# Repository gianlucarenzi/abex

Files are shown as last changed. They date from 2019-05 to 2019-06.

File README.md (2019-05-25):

Atari Bus EXtender for Atari XE Computers
=====================================

This is a Atari PBI & ECI Bus extender, for adding expansion board with ease,
called Atari Bus EXtender for Atari XE Computers or ABEX for short.

This project expand somehow the Atari 1090XL Bus Expansion in the early 80s
but with a simple layout and using only 3.3v compliant electronics.
No 5V is available on the bus, and all signals are converted to 3.3v level.

The Bus recall somehow the AteoBus from Amiga 1200 Computers but using a
more common nowadays PCI-Express Bus Slots with 64 pins.

Right now there are 2 boards desinged for this bus:

1- Atari DUO Cart (a porting of the famous Uno-Cart Project)

2- Atari MegaRAM (a PortB PIA Emulator) with 1024K RAM memory banked

More boards can be added as soon they do not interfere with the others
like using the PBI Protocol device in available in ROM. For example a simple
RS232 Board can be designed using a STM32F407 as port EXPANDER with R: handler
in internal flash, or a SDCard Hard Drive Simulator can be designed as well.

Even WiFi or Ethernet Controller can be achived flawlessly.

Everything is up to you, using your mind to open the world to this wonderful
machine like Atari 130XE.

Rendered Images
===============
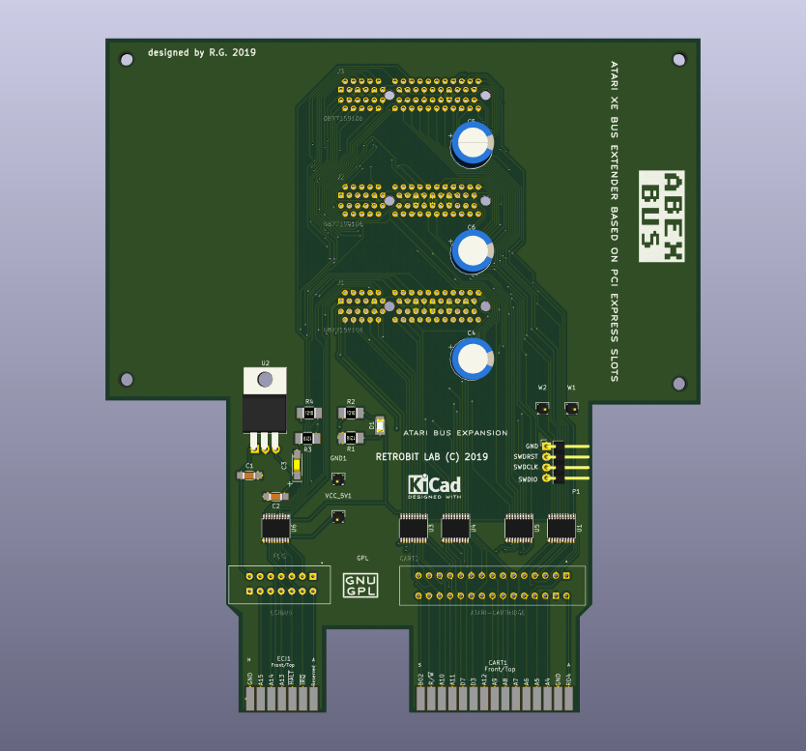
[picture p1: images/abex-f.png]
Board Front
# Front
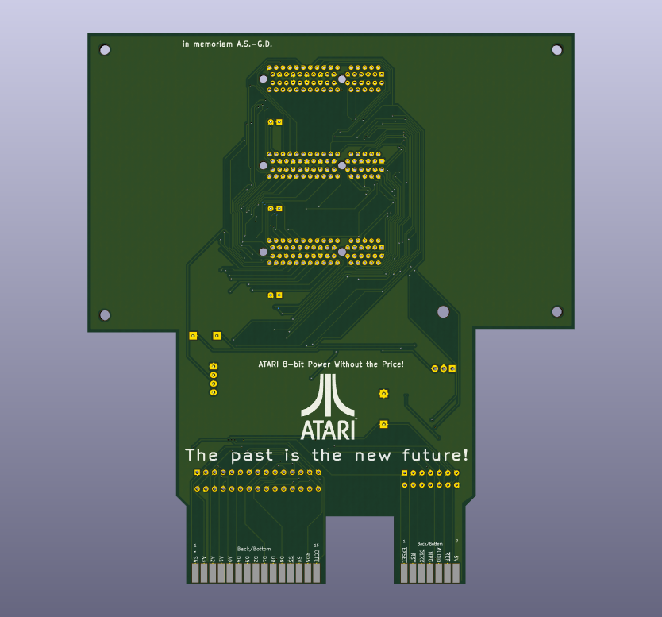
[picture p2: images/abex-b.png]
Board Back
# Back
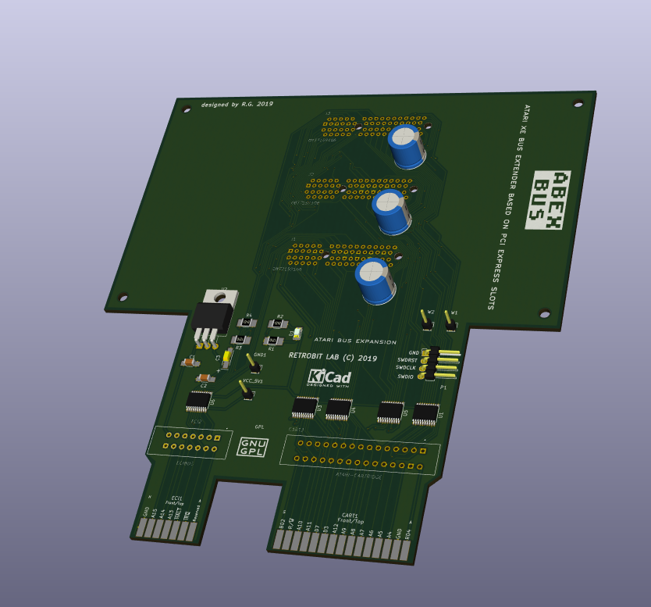
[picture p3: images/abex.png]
Board Overall
# Overall

Hardware License
================
Copyright (C) 2018/2019 Gianluca Renzi <gianlucarenzi@eurek.it> <icjtqr@gmail.com>

The hardware of this project is released as free/open hardware under the
Creative Commons Attribution Share-Alike license. See `LICENSE.hw` for details.

Firmware License
================
Copyright (C) 2019 Gianluca Renzi <icjtqr@gmail.com>

The microcontroller firmware of this project is released as free software,
under the terms of the GNU General Public License v3, or later.  See
`LICENSE.sw` for details.

Software License
================
The host software (amigafloppy tool) is released as free software, under the
terms of the GNU General Public License v3, or later. See `LICENSE.sw` or licence.txt for
details.

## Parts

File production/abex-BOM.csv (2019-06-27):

Id | Designator | Package | Quantity | Designation | Supplier and ref
1 | REF** | KiCad-Logo2_5mm_SilkScreen | 1 | KiCad-Logo2_5mm_SilkScreen
2 | GPL | Symbol_GNU-GPL_SilkScreen_Small | 1 | Symbol_GNU-GPL_CopperTop_Small
3 | LOGO | ABEX_Logo_22mmx11mm_WB | 1 | LOGO
4 | C1,C7,C8,C9 | C_1206_HandSoldering | 4 | 10u
5 | C2 | C_1206_HandSoldering | 1 | 100n
6 | C3 | TantalC_SizeA_EIA-3216_HandSoldering | 1 | 22u
7 | CART1 | ATARI-LEFT-CARTRIDGE | 1 | ATARI-CARTRIDGE
8 | CART2 | TE_5530843-2_15X2_CART_EDGE_CONNECTOR | 1 | ATARI-CARTRIDGE
9 | D1 | LED_1206 | 1 | LED GREEN
10 | ECI1 | ATARI-XE-ECI-SLOT | 1 | ECIBUS
11 | R1 | R_1210_HandSoldering | 1 | 1.5K
12 | R2,R4,R3 | R_1210_HandSoldering | 3 | 0
13 | U1,U3,U4,U5,U6 | SSOP-20_4.4x6.5mm_Pitch0.65mm | 5 | TXB0108-PW
14 | W1,W2,GND1,VCC_5V1 | Pin_Header_Straight_1x01 | 4 | TEST_1P
15 | J4,J5,J6,J7 | MountingHole_3mm | 4 | Conn_01x01
16 | ECI2 | ECI_BUS_7X2_EDGE_CONNECTOR | 1 | ECIBUS
17 | P1 | Pin_Header_Angled_1x04 | 1 | CONN_01X04
18 | C4,C5,C6 | CP_Radial_D10.0mm_P2.50mm_3D | 3 | 10u
19 | U2 | MCP_1827S_TO-220-3_Horizontal_TabDown | 1 | MCP1827S-1.5A-TO-220-3
20 | J1,J2,J3 | MOLEX_0877159106 | 3 | 0877159106
21 | ATARILOGO | atari_fuji_SilkScreen_21.2x25-Rev | 1 | LOGO

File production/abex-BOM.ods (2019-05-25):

Id | Designator | Package | Quantity | Designation | Codice componente | Codice produttore | Descrizione
1 | J1,J2,J3 | ISA_BUS_CONNECTOR_62PIN | 3 | Bus_ISA_8bit_for_ATARI_8bit | EBC31DCWN-S371-ND | EBC31DCWN-S371 | CONN ISA FEMALE 62POS 0.100 GOLD
2 | C1 | C_1206_HandSoldering | 1 | 10u | 445-9985-1-ND | CGA5L1X7R1E106M160AD | CAP CER 10UF 25V X7R 1206 EPOXY
3 | C2 | C_1206_HandSoldering | 1 | 100n | 720-1803-1-ND | VJ1206Y104KXJPW1BC | CAP CER 0.1UF 16V X7R 1206
4 | C3 | TantalC_SizeA_EIA-3216_HandSoldering | 1 | 22u | 399-3692-1-ND | T491A226M010AT | CAP TANT 22UF 20% 10V 1206
5 | CART1 | ATARI-LEFT-CARTRIDGE | 1 | ATARI-CARTRIDGE
6 | CART2 | TE_5530843-2_15X2_CART_EDGE_CONNECTOR | 1 | ATARI-CARTRIDGE | A31715-ND | 5530843-2 | CONN CARDEDGE FEMALE 30POS 0.100
7 | D1 | LED_1206 | 1 | LED GREEN | 160-1166-1-ND | LTST-C150AKT | LED AMBER CLEAR SMD
8 | ECI1 | ATARI-XE-ECI-SLOT | 1 | ECIBUS
9 | R1 | R_1210_HandSoldering | 1 | 1.5K | RMCF1210FT1K50CT-ND | RMCF1210FT1K50 | RES 1.5K OHM 1% 1/3W 1210
10 | R2,R4,R5 | R_1210_HandSoldering | 3 | 0 | RMCF1210ZT0R00CT-ND | RMCF1210ZT0R00 | RES 0 OHM JUMPER 1/2W 1210
11 | U1,U2,U3,U4,U5 | SSOP-20_4.4x6.5mm_Pitch0.65mm | 5 | TXB0108-PW | 296-21527-1-ND | TXB0108PWR | IC TRNSLTR BIDIRECTIONAL 20TSSOP
12 | U6 | MCP_1827S_TO-220-3_Horizontal_TabDown | 1 | MCP1827S-1.5A-TO-220-3 | MCP1827S-3302E/AB-ND | MCP1827S-3302E/AB | IC REG LINEAR 3.3V 1.5A TO220-3
13 | W1,W2,GND1,VCC_5V1 | Pin_Header_Straight_1x01 | 4 | TEST_1P | 609-3301-ND | 68002-210HLF | CONN HEADER VERT 10POS 2.54MM
14 | J4,J5,J6,J7 | MountingHole_3mm | 4 | Conn_01x01 | 609-3301-ND | 68002-210HLF | CONN HEADER VERT 10POS 2.54MM
15 | P1 | Pin_Header_Angled_1x04 | 1 | CONN_01X04 | 609-3407-ND | 68016-404HLF | CONN HEADER R/A 4POS 2.54MM
16 | ECI2 | ECI_BUS_7X2_EDGE_CONNECTOR | 1 | ECIBUS | S9712-ND | ECC07DRTN | CONN EDGE DUAL FMALE 14POS 0.100
17 | GNU | Symbol_GNU-GPL_SilkScreen_Small | 1 | Symbol_GNU-GPL_CopperTop_Small
18 | REF** | KiCad-Logo2_8mm_SilkScreen | 1 | KiCad-Logo2_8mm_SilkScreen
19 | G*** | ABEX_Logo_22mmx11mm_WB | 1 | LOGO
20 | G*** | atari_800_XL_BW_25x25 | 1 | LOGO

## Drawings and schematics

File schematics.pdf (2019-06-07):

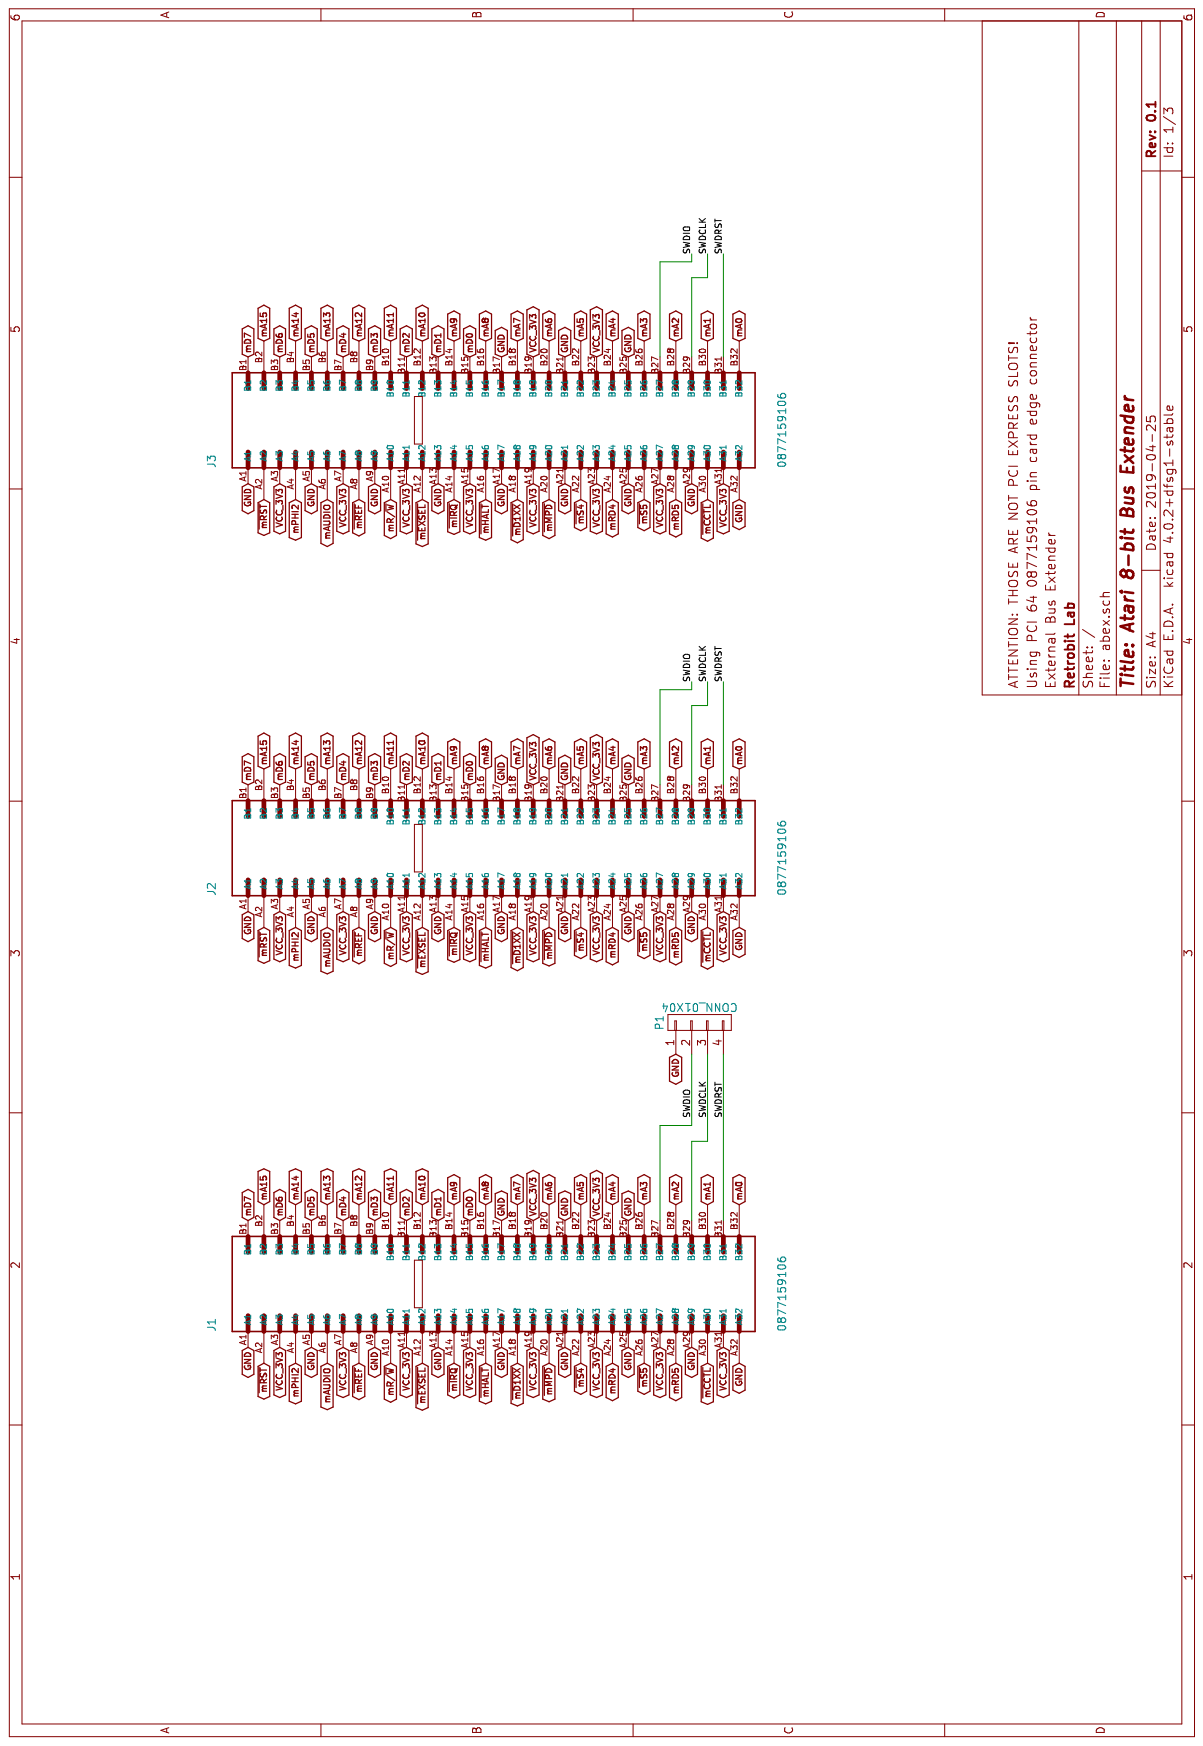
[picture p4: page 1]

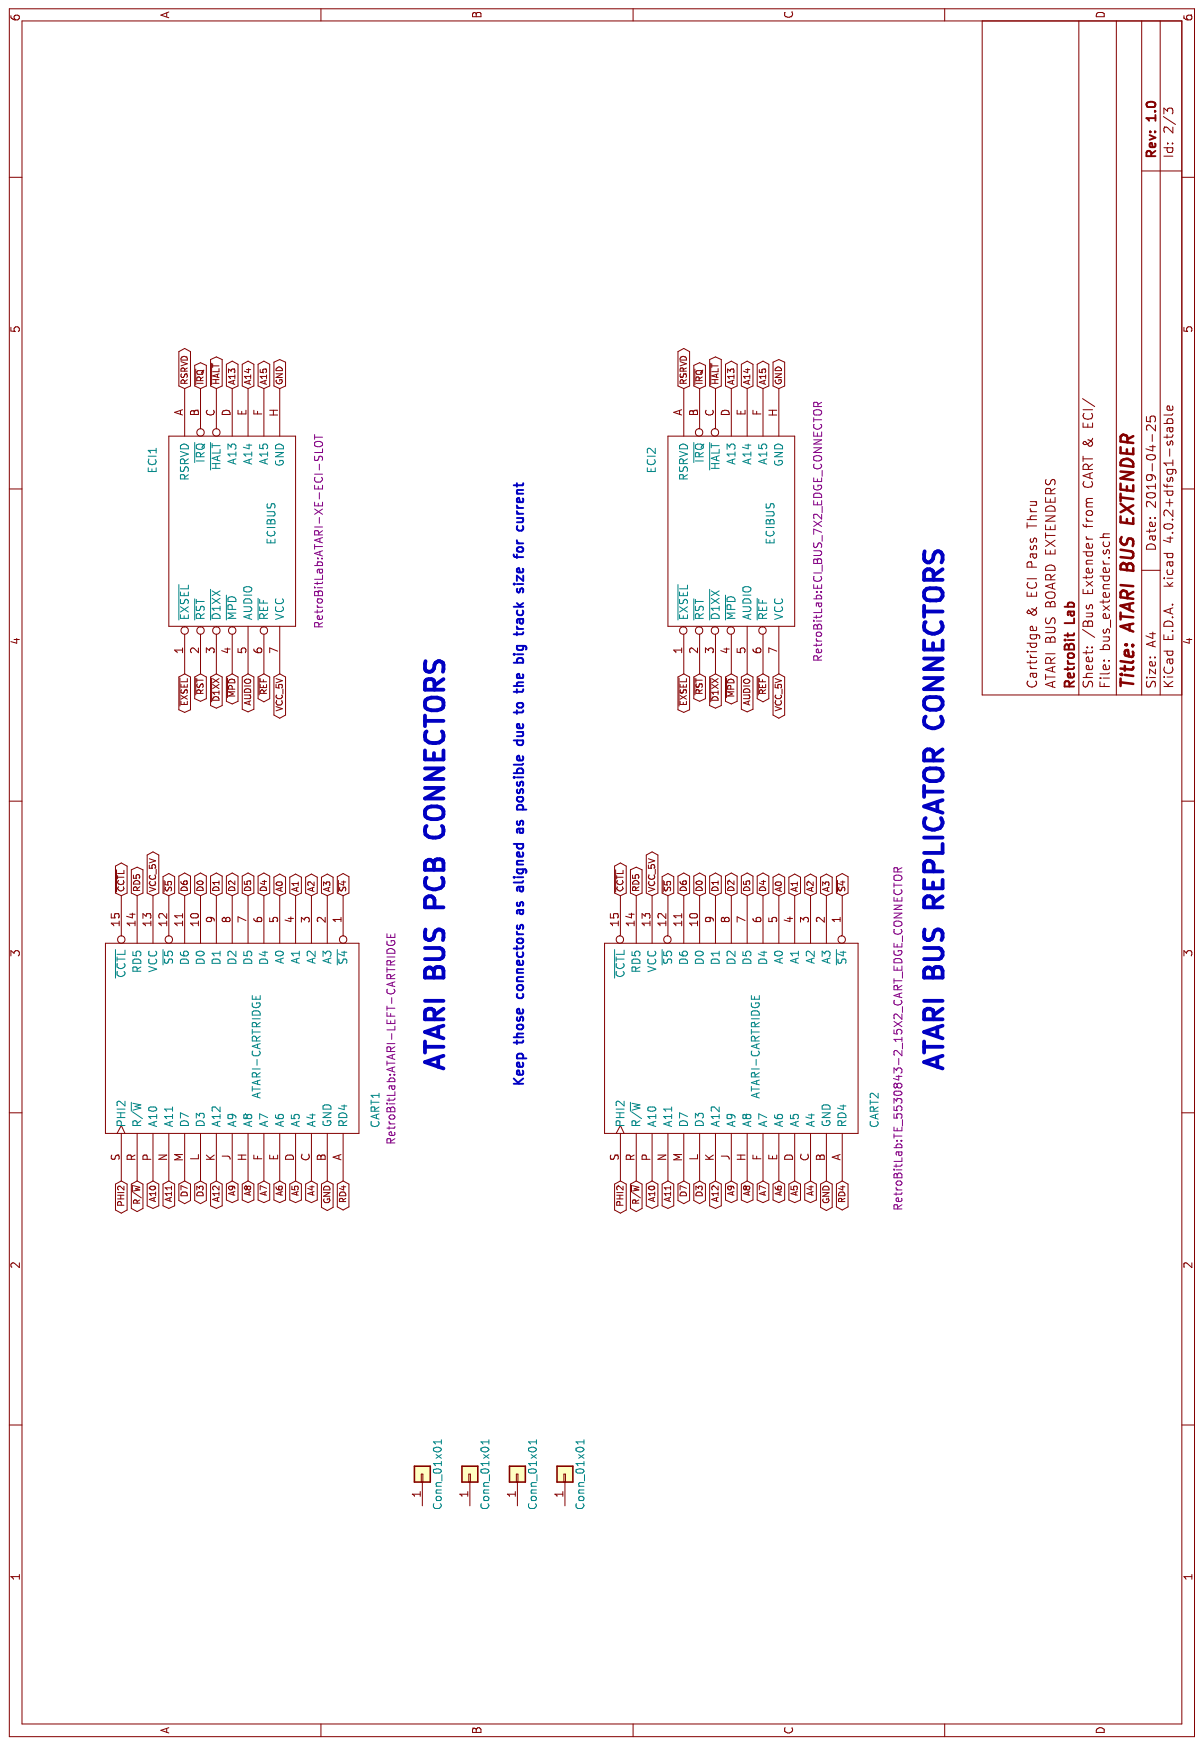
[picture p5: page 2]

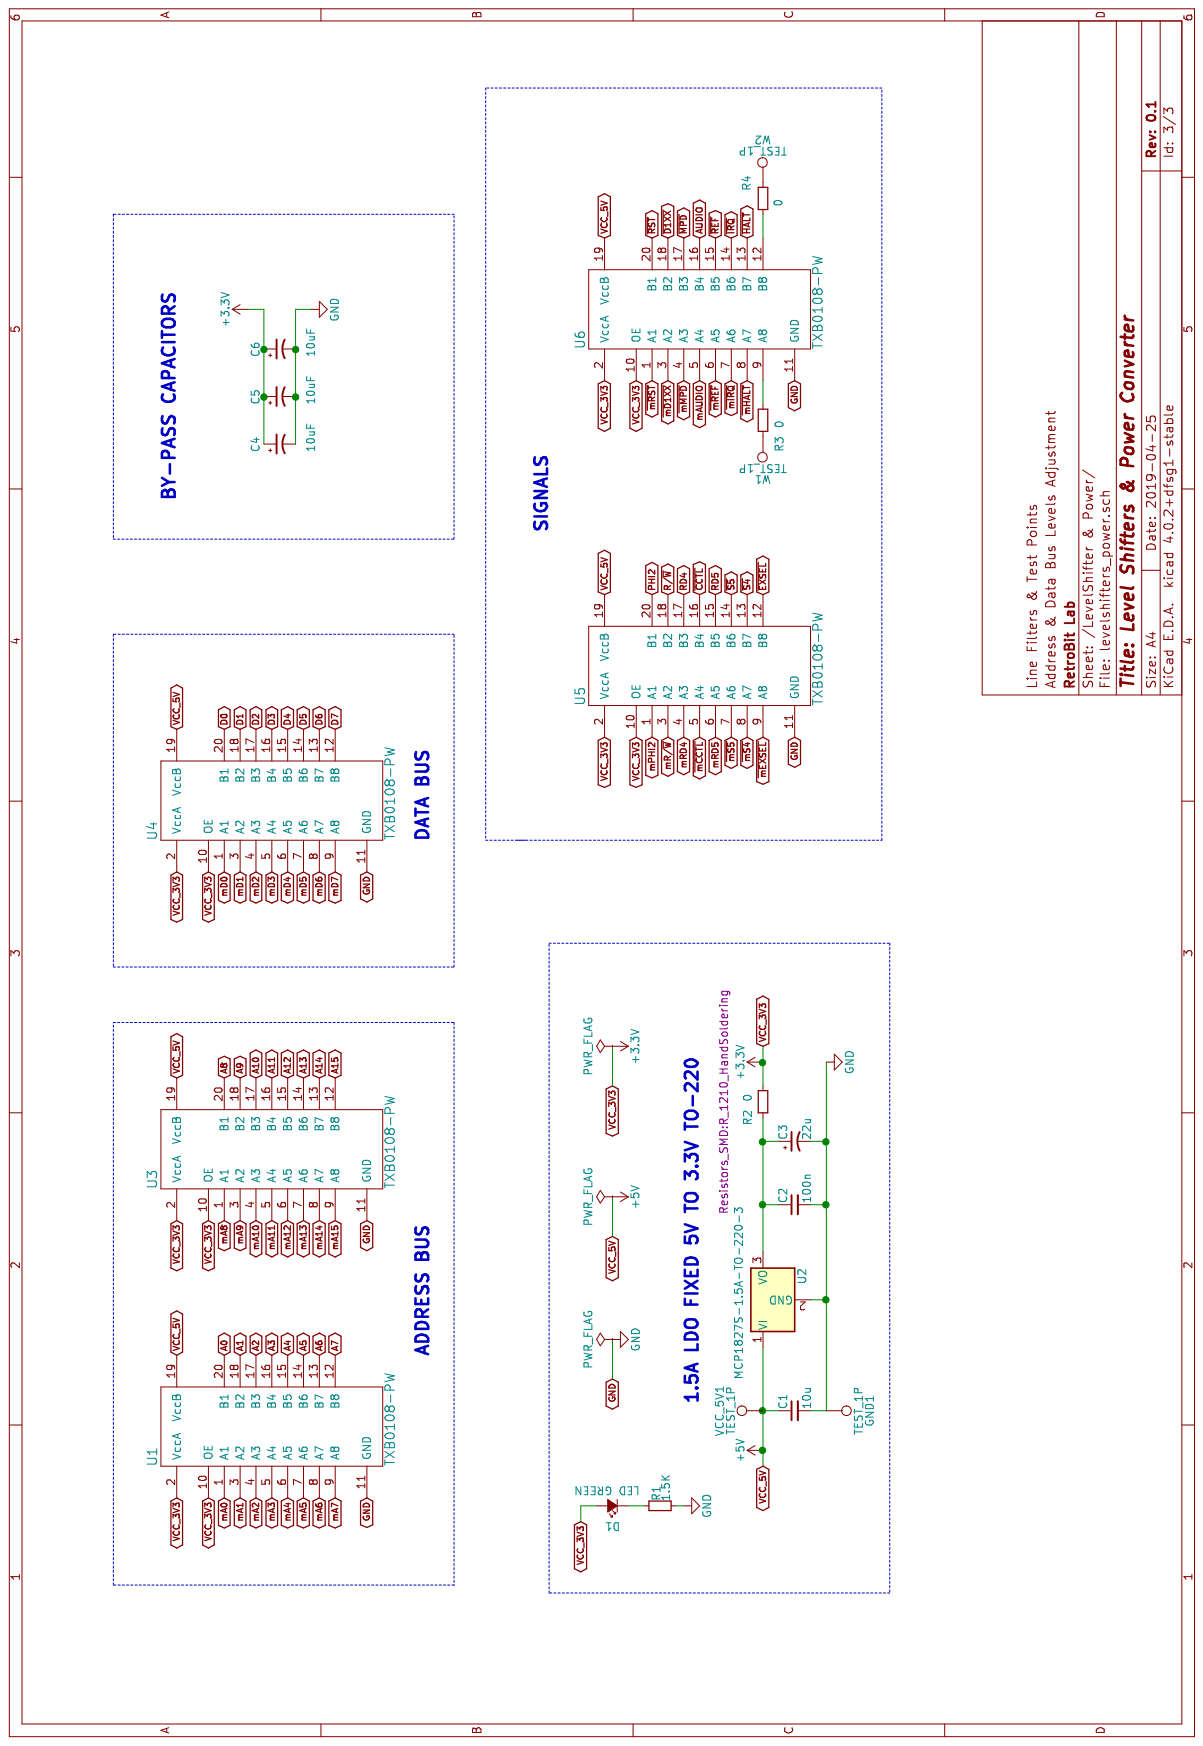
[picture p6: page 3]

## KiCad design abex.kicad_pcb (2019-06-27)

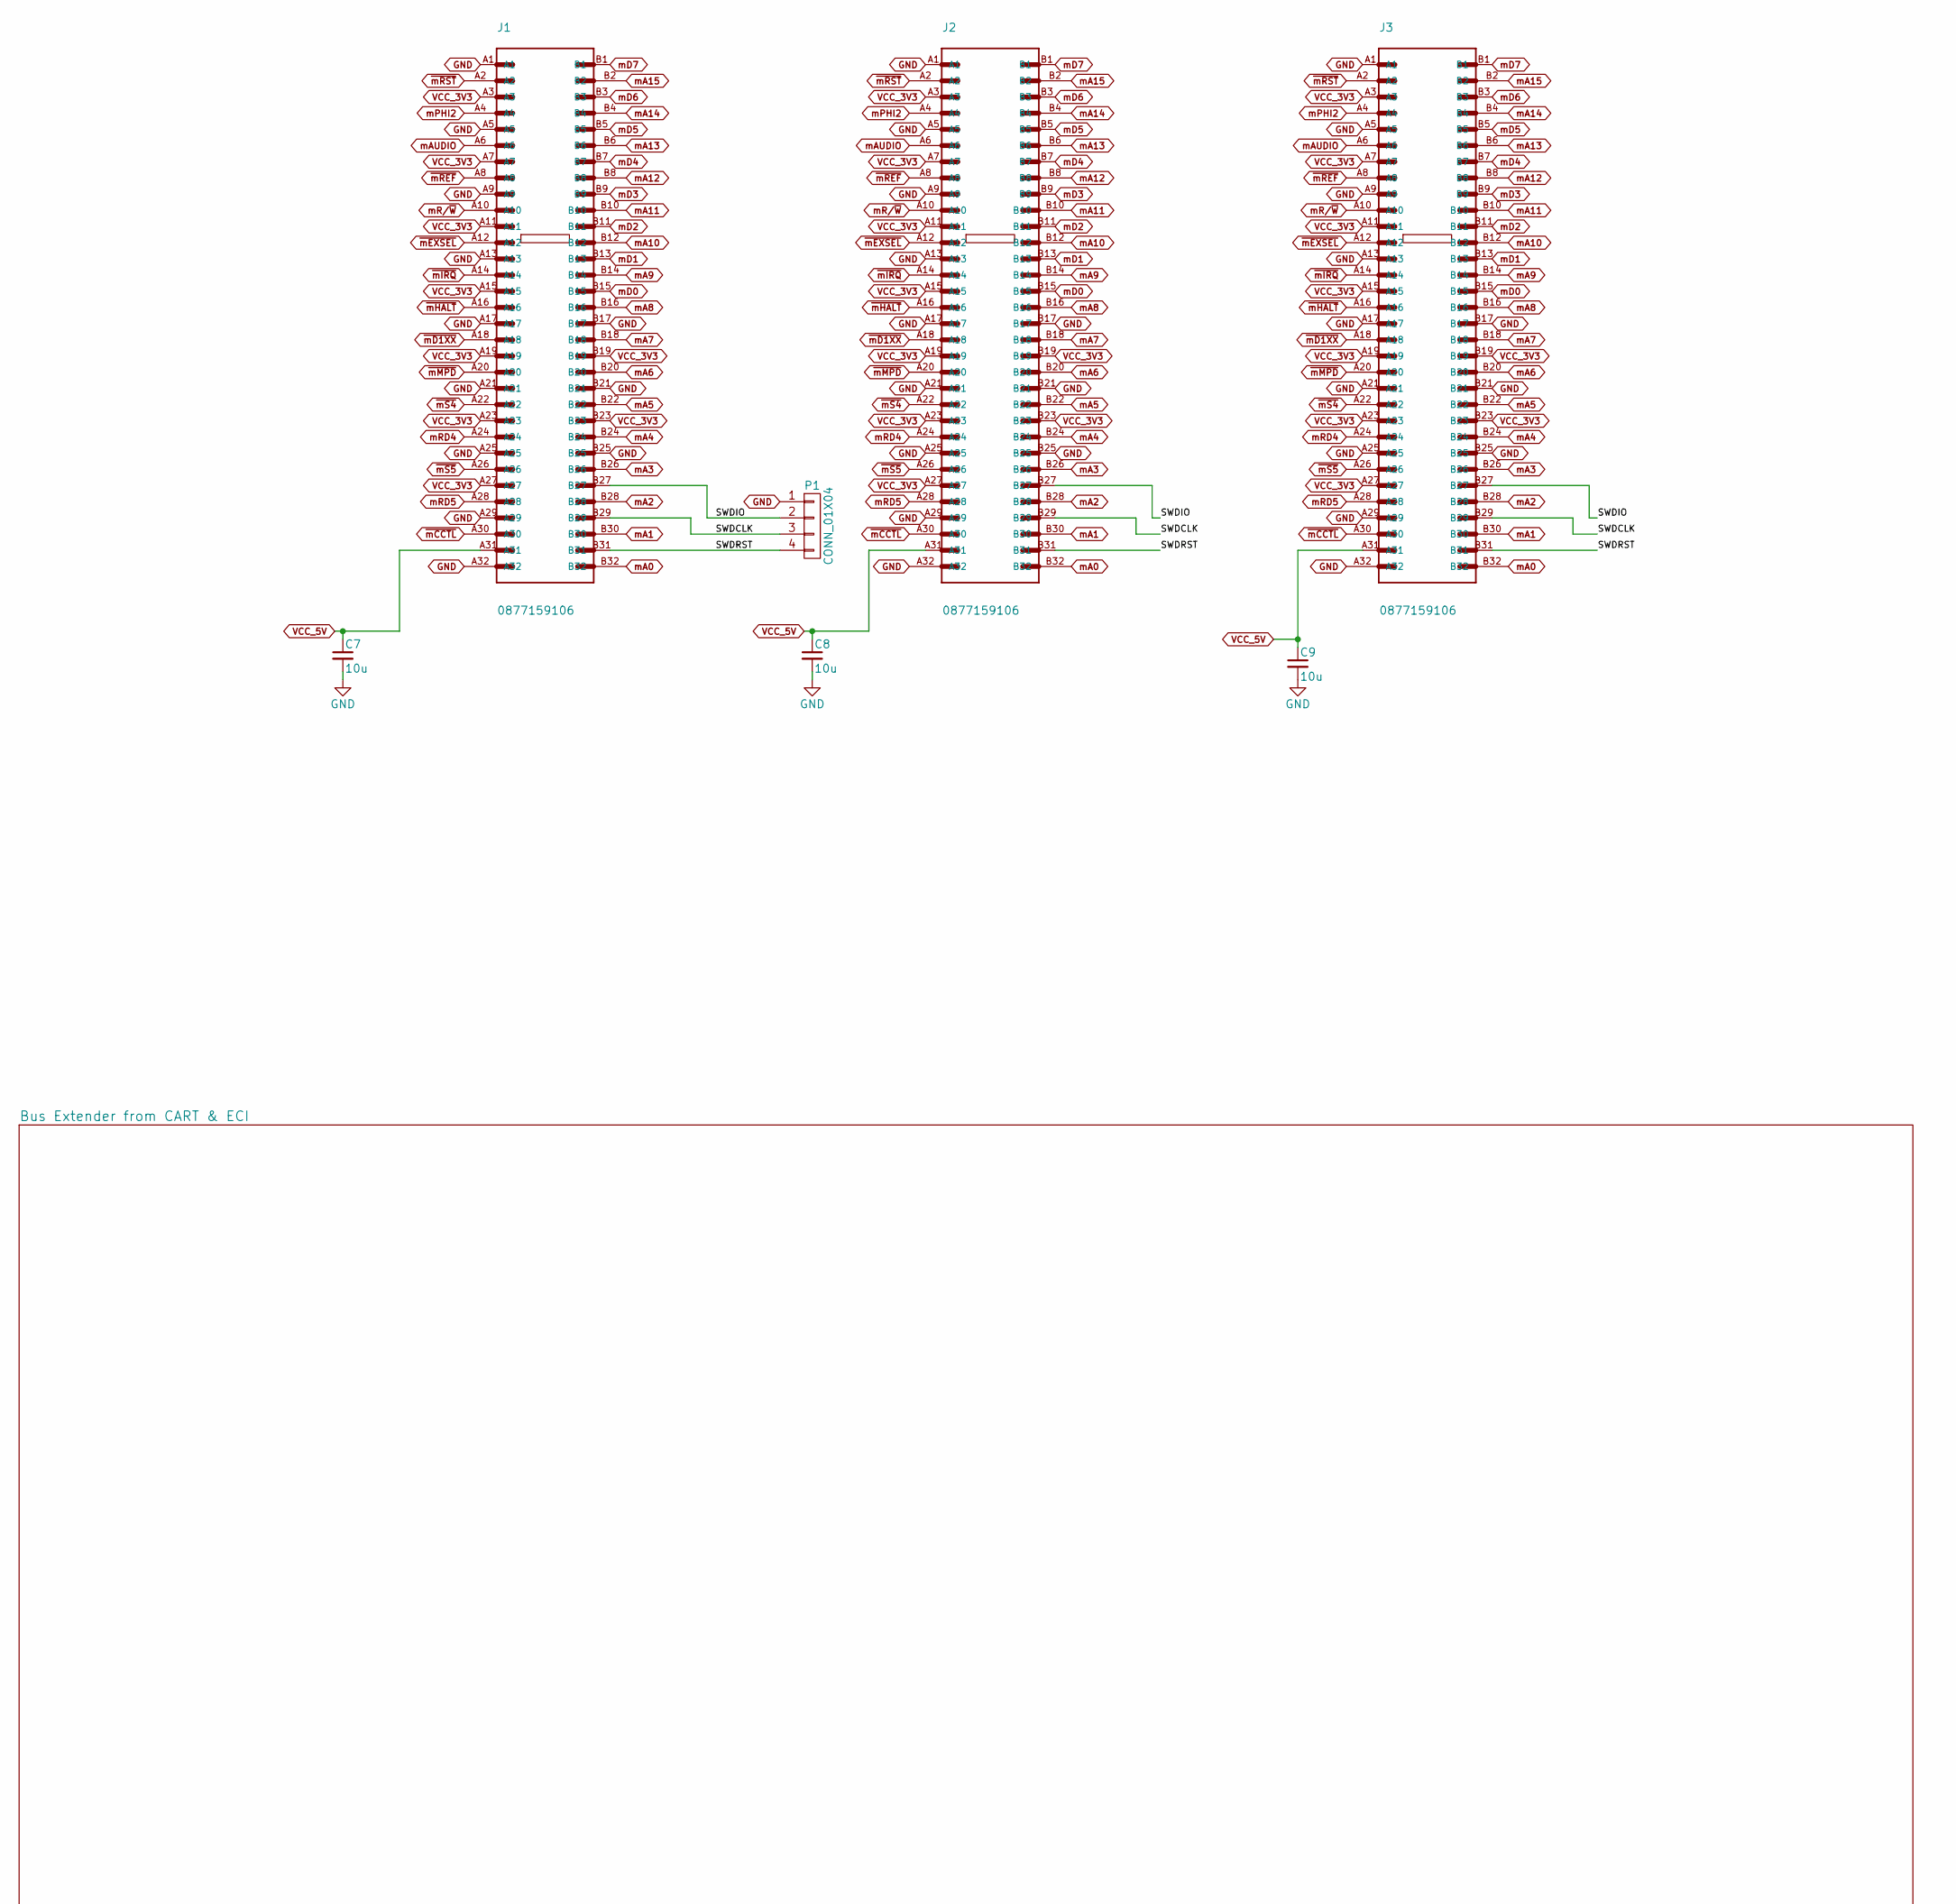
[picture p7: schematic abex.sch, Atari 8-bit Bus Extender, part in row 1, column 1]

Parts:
C7, C8, C9: 10u; C_1206_HandSoldering
J1, J2, J3: 0877159106; MOLEX_0877159106
P1: CONN_01X04; Pin_Header_Angled_1x04

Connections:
/SWDCLK: J1.B29, J2.B29, J3.B29, P1.3
/SWDIO: J1.B27, J2.B27, J3.B27, P1.2
/SWDRST: J1.B31, J2.B31, J3.B31, P1.4
GND: C7.2, C8.2, C9.2, J1.A1, J1.A5, J1.A9, J1.A13, J1.A17, J1.A21, J1.A25, J1.A29, J1.A32, J1.B17, J1.B21, J1.B25, J2.A1, J2.A5, J2.A9, J2.A13, J2.A17, J2.A21, J2.A25, J2.A29, J2.A32, J2.B17, J2.B21, J2.B25, J3.A1, J3.A5, J3.A9, J3.A13, J3.A17, J3.A21, J3.A25, J3.A29, J3.A32, J3.B17, J3.B21, J3.B25, P1.1; also elsewhere on the board
VCC_3V3: J1.A3, J1.A7, J1.A11, J1.A15, J1.A19, J1.A23, J1.A27, J1.B19, J1.B23, J2.A3, J2.A7, J2.A11, J2.A15, J2.A19, J2.A23, J2.A27, J2.B19, J2.B23, J3.A3, J3.A7, J3.A11, J3.A15, J3.A19, J3.A23, J3.A27, J3.B19, J3.B23; also elsewhere on the board
VCC_5V: C7.1, C8.1, C9.1, J1.A31, J2.A31, J3.A31; also elsewhere on the board
mA0: J1.B32, J2.B32, J3.B32; also elsewhere on the board
mA1: J1.B30, J2.B30, J3.B30; also elsewhere on the board
mA2: J1.B28, J2.B28, J3.B28; also elsewhere on the board
mA3: J1.B26, J2.B26, J3.B26; also elsewhere on the board
mA4: J1.B24, J2.B24, J3.B24; also elsewhere on the board
mA5: J1.B22, J2.B22, J3.B22; also elsewhere on the board
mA6: J1.B20, J2.B20, J3.B20; also elsewhere on the board
mA7: J1.B18, J2.B18, J3.B18; also elsewhere on the board
mA8: J1.B16, J2.B16, J3.B16; also elsewhere on the board
mA9: J1.B14, J2.B14, J3.B14; also elsewhere on the board
mA10: J1.B12, J2.B12, J3.B12; also elsewhere on the board
mA11: J1.B10, J2.B10, J3.B10; also elsewhere on the board
mA12: J1.B8, J2.B8, J3.B8; also elsewhere on the board
mA13: J1.B6, J2.B6, J3.B6; also elsewhere on the board
mA14: J1.B4, J2.B4, J3.B4; also elsewhere on the board
mA15: J1.B2, J2.B2, J3.B2; also elsewhere on the board
mAUDIO: J1.A6, J2.A6, J3.A6; also elsewhere on the board
mD0: J1.B15, J2.B15, J3.B15; also elsewhere on the board
mD1: J1.B13, J2.B13, J3.B13; also elsewhere on the board
mD2: J1.B11, J2.B11, J3.B11; also elsewhere on the board
mD3: J1.B9, J2.B9, J3.B9; also elsewhere on the board
mD4: J1.B7, J2.B7, J3.B7; also elsewhere on the board
mD5: J1.B5, J2.B5, J3.B5; also elsewhere on the board
mD6: J1.B3, J2.B3, J3.B3; also elsewhere on the board
mD7: J1.B1, J2.B1, J3.B1; also elsewhere on the board
mPHI2: J1.A4, J2.A4, J3.A4; also elsewhere on the board
mR/~W: J1.A10, J2.A10, J3.A10; also elsewhere on the board
mRD4: J1.A24, J2.A24, J3.A24; also elsewhere on the board
mRD5: J1.A28, J2.A28, J3.A28; also elsewhere on the board
~mCCTL: J1.A30, J2.A30, J3.A30; also elsewhere on the board
~mD1XX: J1.A18, J2.A18, J3.A18; also elsewhere on the board
~mEXSEL: J1.A12, J2.A12, J3.A12; also elsewhere on the board
~mHALT: J1.A16, J2.A16, J3.A16; also elsewhere on the board
~mIRQ: J1.A14, J2.A14, J3.A14; also elsewhere on the board
~mMPD: J1.A20, J2.A20, J3.A20; also elsewhere on the board
~mREF: J1.A8, J2.A8, J3.A8; also elsewhere on the board
~mRST: J1.A2, J2.A2, J3.A2; also elsewhere on the board
~mS4: J1.A22, J2.A22, J3.A22; also elsewhere on the board
~mS5: J1.A26, J2.A26, J3.A26; also elsewhere on the board

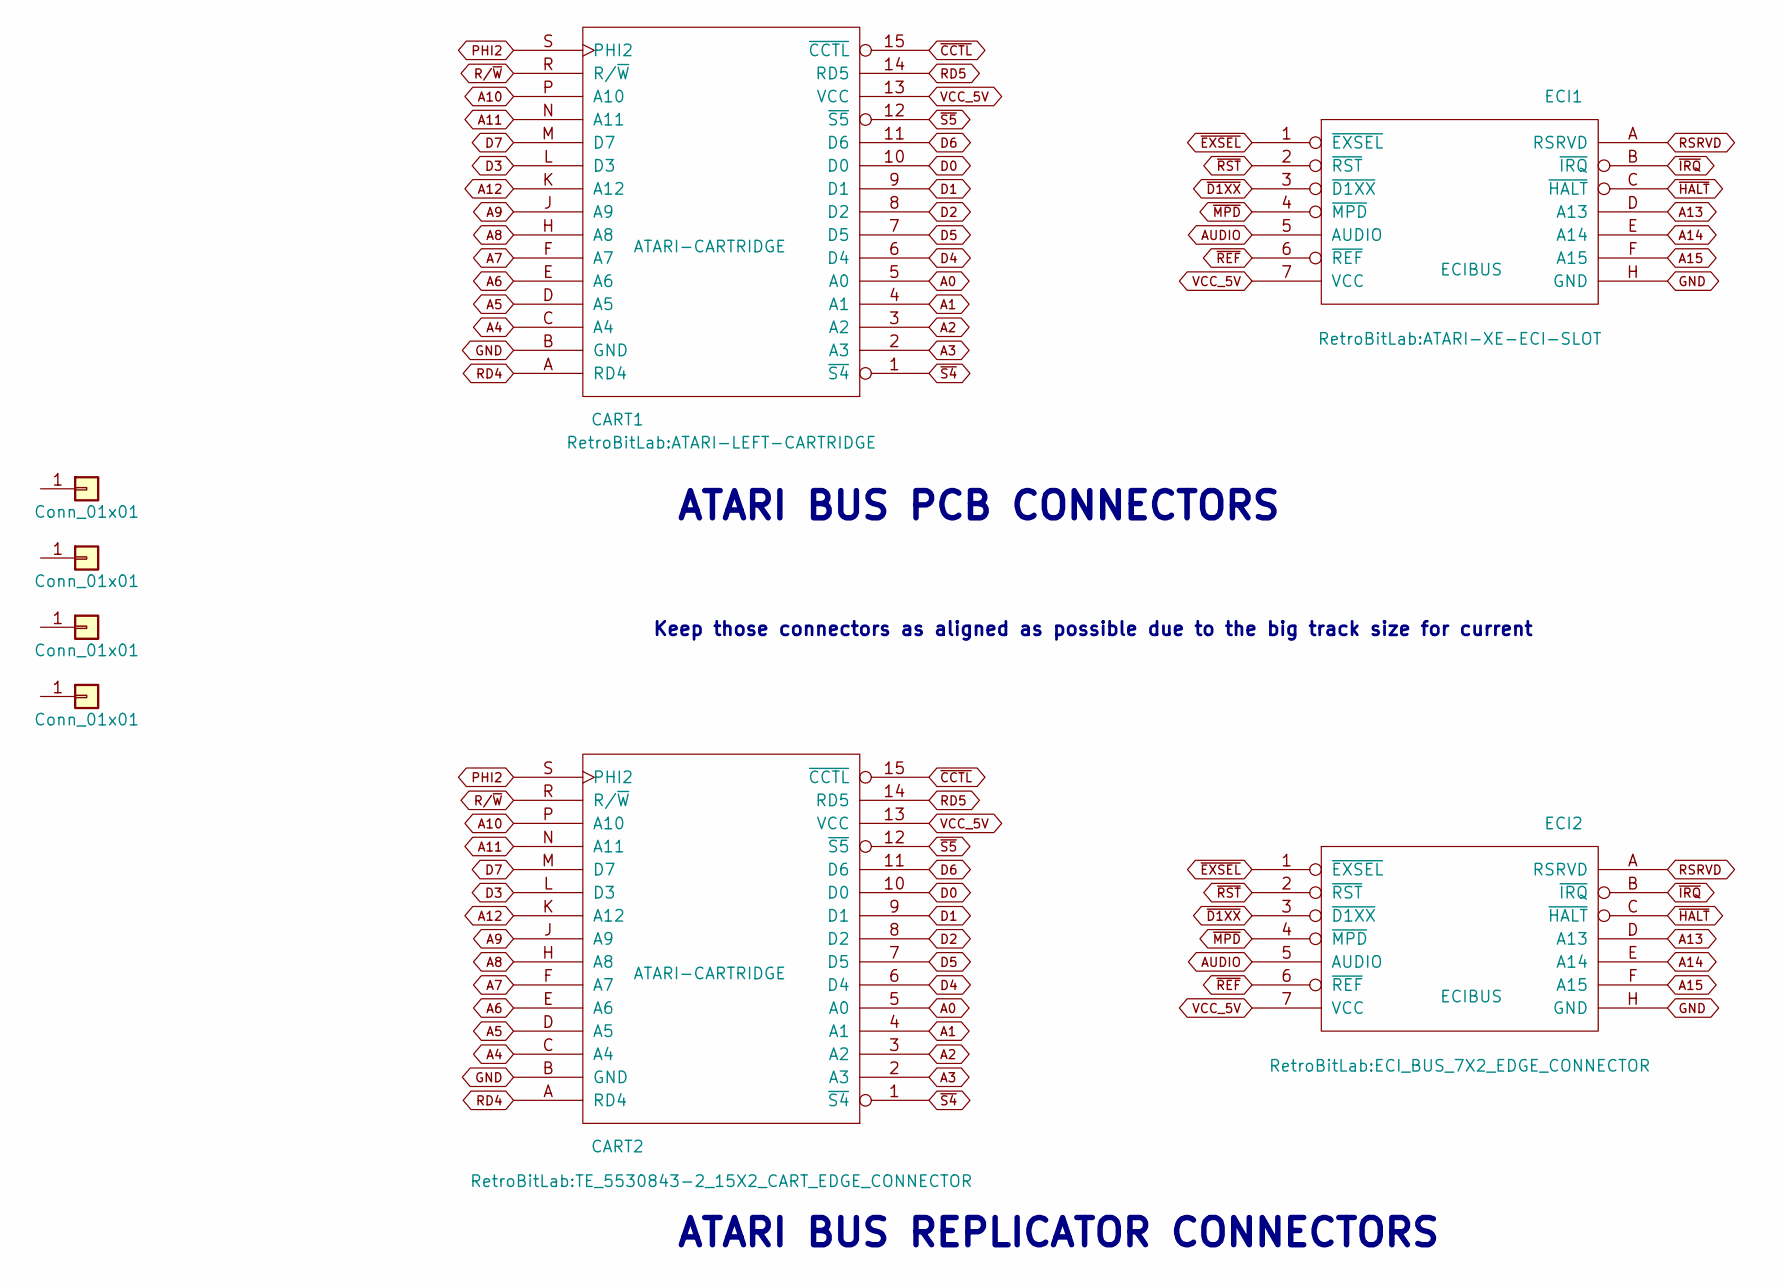
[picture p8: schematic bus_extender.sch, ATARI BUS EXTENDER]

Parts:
CART1: ATARI-CARTRIDGE; ATARI-LEFT-CARTRIDGE
CART2: ATARI-CARTRIDGE; TE_5530843-2_15X2_CART_EDGE_CONNECTOR
ECI1: ECIBUS; ATARI-XE-ECI-SLOT
ECI2: ECIBUS; ECI_BUS_7X2_EDGE_CONNECTOR
J4, J5, J6, J7: Conn_01x01; MountingHole_3mm

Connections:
A0: CART1.5 (A0), CART2.5 (A0); also elsewhere on the board
A1: CART1.4 (A1), CART2.4 (A1); also elsewhere on the board
A2: CART1.3 (A2), CART2.3 (A2); also elsewhere on the board
A3: CART1.2 (A3), CART2.2 (A3); also elsewhere on the board
A4: CART1.C (A4), CART2.C (A4); also elsewhere on the board
A5: CART1.D (A5), CART2.D (A5); also elsewhere on the board
A6: CART1.E (A6), CART2.E (A6); also elsewhere on the board
A7: CART1.F (A7), CART2.F (A7); also elsewhere on the board
A8: CART1.H (A8), CART2.H (A8); also elsewhere on the board
A9: CART1.J (A9), CART2.J (A9); also elsewhere on the board
A10: CART1.P (A10), CART2.P (A10); also elsewhere on the board
A11: CART1.N (A11), CART2.N (A11); also elsewhere on the board
A12: CART1.K (A12), CART2.K (A12); also elsewhere on the board
A13: ECI1.D (A13), ECI2.D (A13); also elsewhere on the board
A14: ECI1.E (A14), ECI2.E (A14); also elsewhere on the board
A15: ECI1.F (A15), ECI2.F (A15); also elsewhere on the board
AUDIO: ECI1.5 (AUDIO), ECI2.5 (AUDIO); also elsewhere on the board
D0: CART1.10 (D0), CART2.10 (D0); also elsewhere on the board
D1: CART1.9 (D1), CART2.9 (D1); also elsewhere on the board
D2: CART1.8 (D2), CART2.8 (D2); also elsewhere on the board
D3: CART1.L (D3), CART2.L (D3); also elsewhere on the board
D4: CART1.6 (D4), CART2.6 (D4); also elsewhere on the board
D5: CART1.7 (D5), CART2.7 (D5); also elsewhere on the board
D6: CART1.11 (D6), CART2.11 (D6); also elsewhere on the board
D7: CART1.M (D7), CART2.M (D7); also elsewhere on the board
GND: CART1.B (GND), CART2.B (GND), ECI1.H (GND), ECI2.H (GND); also elsewhere on the board
PHI2: CART1.S (PHI2), CART2.S (PHI2); also elsewhere on the board
R/~W: CART1.R (R/~W), CART2.R (R/~W); also elsewhere on the board
RD4: CART1.A (RD4), CART2.A (RD4); also elsewhere on the board
RD5: CART1.14 (RD5), CART2.14 (RD5); also elsewhere on the board
RSRVD: ECI1.A (RSRVD), ECI2.A (RSRVD)
VCC_5V: CART1.13 (VCC), CART2.13 (VCC), ECI1.7 (VCC), ECI2.7 (VCC); also elsewhere on the board
~CCTL: CART1.15 (~CCTL), CART2.15 (~CCTL); also elsewhere on the board
~D1XX: ECI1.3 (~D1XX), ECI2.3 (~D1XX); also elsewhere on the board
~EXSEL: ECI1.1 (~EXSEL), ECI2.1 (~EXSEL); also elsewhere on the board
~HALT: ECI1.C (~HALT), ECI2.C (~HALT); also elsewhere on the board
~IRQ: ECI1.B (~IRQ), ECI2.B (~IRQ); also elsewhere on the board
~MPD: ECI1.4 (~MPD), ECI2.4 (~MPD); also elsewhere on the board
~REF: ECI1.6 (~REF), ECI2.6 (~REF); also elsewhere on the board
~RST: ECI1.2 (~RST), ECI2.2 (~RST); also elsewhere on the board
~S4: CART1.1 (~S4), CART2.1 (~S4); also elsewhere on the board
~S5: CART1.12 (~S5), CART2.12 (~S5); also elsewhere on the board

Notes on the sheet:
ATARI BUS PCB CONNECTORS
ATARI BUS REPLICATOR CONNECTORS
Keep those connectors as aligned as possible due to the big track size for current

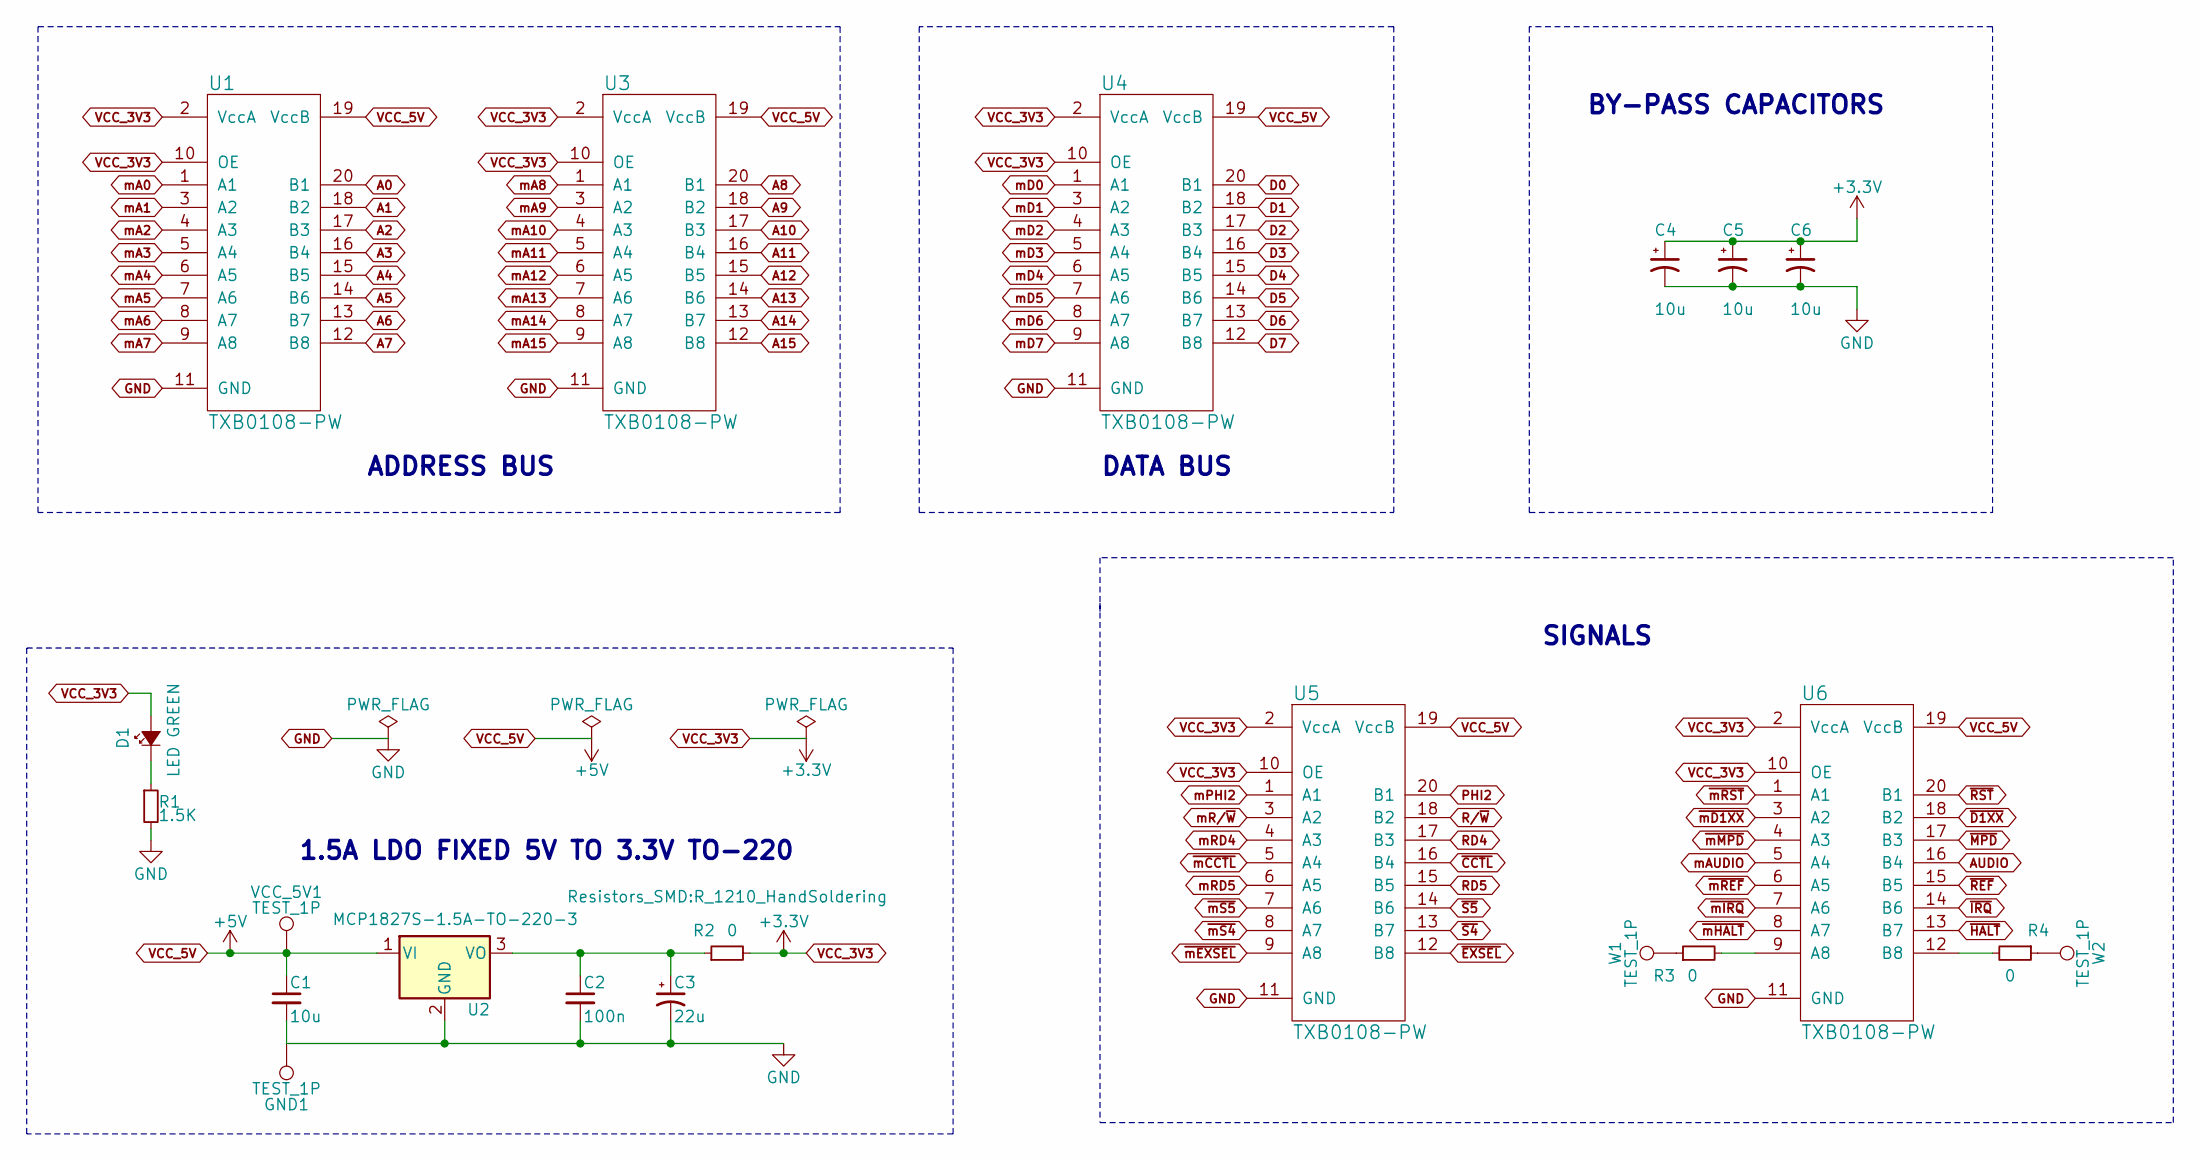
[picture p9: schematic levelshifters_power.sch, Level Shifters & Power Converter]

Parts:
C1: 10u; C_1206_HandSoldering
C2: 100n; C_1206_HandSoldering
C3: 22u; TantalC_SizeA_EIA-3216_HandSoldering
C4, C5, C6: 10u; CP_Radial_D10.0mm_P2.50mm_3D
D1: LED GREEN; LED_1206
GND1: TEST_1P; Pin_Header_Straight_1x01
R1: 1.5K; R_1210_HandSoldering
R2, R3, R4: 0; R_1210_HandSoldering
U1, U3, U4, U5, U6: TXB0108-PW; SSOP-20_4.4x6.5mm_Pitch0.65mm
U2: MCP1827S-1.5A-TO-220-3; MCP_1827S_TO-220-3_Horizontal_TabDown
VCC_5V1: TEST_1P; Pin_Header_Straight_1x01
W1, W2: TEST_1P; Pin_Header_Straight_1x01

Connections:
A0: U1.20 (B1); also elsewhere on the board
A1: U1.18 (B2); also elsewhere on the board
A2: U1.17 (B3); also elsewhere on the board
A3: U1.16 (B4); also elsewhere on the board
A4: U1.15 (B5); also elsewhere on the board
A5: U1.14 (B6); also elsewhere on the board
A6: U1.13 (B7); also elsewhere on the board
A7: U1.12 (B8); also elsewhere on the board
A8: U3.20 (B1); also elsewhere on the board
A9: U3.18 (B2); also elsewhere on the board
A10: U3.17 (B3); also elsewhere on the board
A11: U3.16 (B4); also elsewhere on the board
A12: U3.15 (B5); also elsewhere on the board
A13: U3.14 (B6); also elsewhere on the board
A14: U3.13 (B7); also elsewhere on the board
A15: U3.12 (B8); also elsewhere on the board
AUDIO: U6.16 (B4); also elsewhere on the board
D0: U4.20 (B1); also elsewhere on the board
D1: U4.18 (B2); also elsewhere on the board
D2: U4.17 (B3); also elsewhere on the board
D3: U4.16 (B4); also elsewhere on the board
D4: U4.15 (B5); also elsewhere on the board
D5: U4.14 (B6); also elsewhere on the board
D6: U4.13 (B7); also elsewhere on the board
D7: U4.12 (B8); also elsewhere on the board
GND: C1.2, C2.2, C3.2, C4.2, C5.2, C6.2, GND1.1, R1.2, U1.11 (GND), U2.2 (GND), U3.11 (GND), U4.11 (GND), U5.11 (GND), U6.11 (GND); also elsewhere on the board
unnamed: C2.1, C3.1, R2.1, U2.3 (VO)
unnamed: D1.1 (K), R1.1
unnamed: R3.1, W1.1
unnamed: R3.2, U6.9 (A8)
unnamed: R4.1, W2.1
unnamed: R4.2, U6.12 (B8)
PHI2: U5.20 (B1); also elsewhere on the board
R/~W: U5.18 (B2); also elsewhere on the board
RD4: U5.17 (B3); also elsewhere on the board
RD5: U5.15 (B5); also elsewhere on the board
VCC_3V3: C4.1, C5.1, C6.1, D1.2 (A), R2.2, U1.2 (VccA), U1.10 (OE), U3.2 (VccA), U3.10 (OE), U4.2 (VccA), U4.10 (OE), U5.2 (VccA), U5.10 (OE), U6.2 (VccA), U6.10 (OE); also elsewhere on the board
VCC_5V: C1.1, U1.19 (VccB), U2.1 (VI), U3.19 (VccB), U4.19 (VccB), U5.19 (VccB), U6.19 (VccB), VCC_5V1.1; also elsewhere on the board
mA0: U1.1 (A1); also elsewhere on the board
mA1: U1.3 (A2); also elsewhere on the board
mA2: U1.4 (A3); also elsewhere on the board
mA3: U1.5 (A4); also elsewhere on the board
mA4: U1.6 (A5); also elsewhere on the board
mA5: U1.7 (A6); also elsewhere on the board
mA6: U1.8 (A7); also elsewhere on the board
mA7: U1.9 (A8); also elsewhere on the board
mA8: U3.1 (A1); also elsewhere on the board
mA9: U3.3 (A2); also elsewhere on the board
mA10: U3.4 (A3); also elsewhere on the board
mA11: U3.5 (A4); also elsewhere on the board
mA12: U3.6 (A5); also elsewhere on the board
mA13: U3.7 (A6); also elsewhere on the board
mA14: U3.8 (A7); also elsewhere on the board
mA15: U3.9 (A8); also elsewhere on the board
mAUDIO: U6.5 (A4); also elsewhere on the board
mD0: U4.1 (A1); also elsewhere on the board
mD1: U4.3 (A2); also elsewhere on the board
mD2: U4.4 (A3); also elsewhere on the board
mD3: U4.5 (A4); also elsewhere on the board
mD4: U4.6 (A5); also elsewhere on the board
mD5: U4.7 (A6); also elsewhere on the board
mD6: U4.8 (A7); also elsewhere on the board
mD7: U4.9 (A8); also elsewhere on the board
mPHI2: U5.1 (A1); also elsewhere on the board
mR/~W: U5.3 (A2); also elsewhere on the board
mRD4: U5.4 (A3); also elsewhere on the board
mRD5: U5.6 (A5); also elsewhere on the board
~CCTL: U5.16 (B4); also elsewhere on the board
~D1XX: U6.18 (B2); also elsewhere on the board
~EXSEL: U5.12 (B8); also elsewhere on the board
~HALT: U6.13 (B7); also elsewhere on the board
~IRQ: U6.14 (B6); also elsewhere on the board
~MPD: U6.17 (B3); also elsewhere on the board
~REF: U6.15 (B5); also elsewhere on the board
~RST: U6.20 (B1); also elsewhere on the board
~S4: U5.13 (B7); also elsewhere on the board
~S5: U5.14 (B6); also elsewhere on the board
~mCCTL: U5.5 (A4); also elsewhere on the board
~mD1XX: U6.3 (A2); also elsewhere on the board
~mEXSEL: U5.9 (A8); also elsewhere on the board
~mHALT: U6.8 (A7); also elsewhere on the board
~mIRQ: U6.7 (A6); also elsewhere on the board
~mMPD: U6.4 (A3); also elsewhere on the board
~mREF: U6.6 (A5); also elsewhere on the board
~mRST: U6.1 (A1); also elsewhere on the board
~mS4: U5.8 (A7); also elsewhere on the board
~mS5: U5.7 (A6); also elsewhere on the board

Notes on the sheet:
1.5A LDO FIXED 5V TO 3.3V TO-220
ADDRESS BUS
DATA BUS
SIGNALS
BY-PASS CAPACITORS

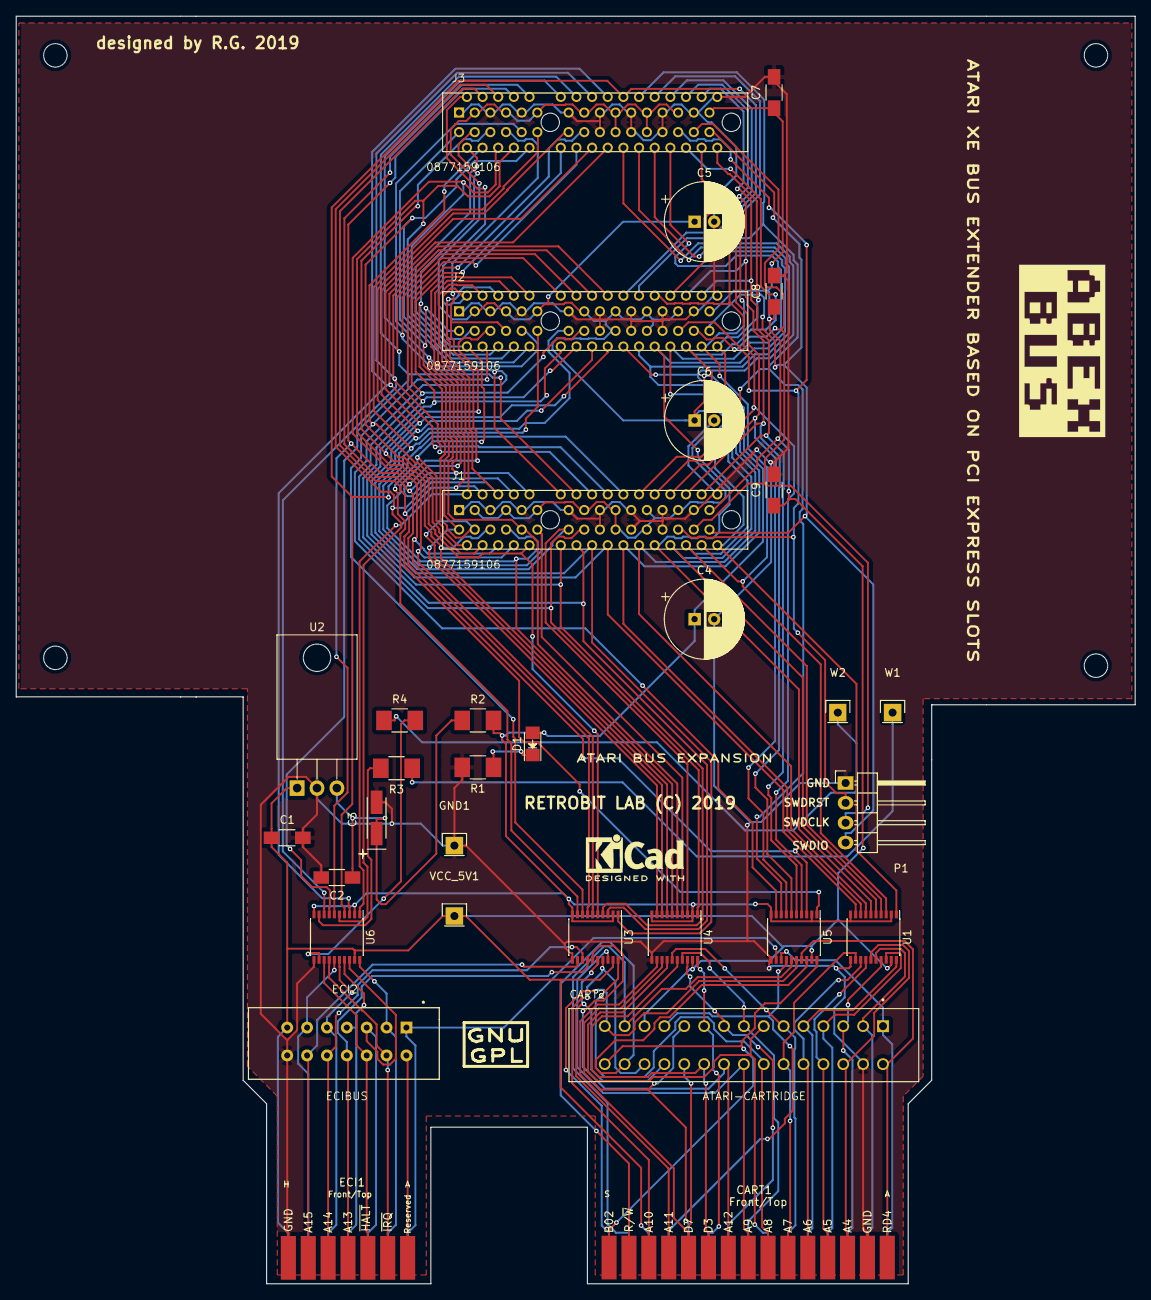
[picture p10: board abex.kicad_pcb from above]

Board: 2 copper layers, 143.0 x 162.0 mm, 39 parts (1 on the bottom side), 91 nets.

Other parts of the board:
ATARILOGO: LOGO; atari_fuji_SilkScreen_21.2x25-Rev
GPL: Symbol_GNU-GPL_CopperTop_Small; Symbol_GNU-GPL_SilkScreen_Small
LOGO: LOGO; ABEX_Logo_22mmx11mm_WB

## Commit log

2019-05-25 First import
    [abex-BOM.csv, abex-BOM.ods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]
2019-06-07 Missing NPTH???
    [abex-NPTH.drl]
2019-06-07 Changed the GPL logo footprint.
    [abex-B.Cu.gbl, abex-B.Mask.gbs, abex-B.Paste.gbp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]
2019-06-27 Added +5VDC on connector (pin 31). All data & bus signals remain 3.3V tolerant.
    Added +5VDC on connector (pin 31). All data & bus signals remain 3.3V
    tolerant. If a card need to have 5V signals it need to have all level
    shifters needed on board.
    [abex-BOM.csv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]
2025-11-01 RetroBitLab library
    [abex.sch, bus_extender.sch, levelshifters_power.sch]

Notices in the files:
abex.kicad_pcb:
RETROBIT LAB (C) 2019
